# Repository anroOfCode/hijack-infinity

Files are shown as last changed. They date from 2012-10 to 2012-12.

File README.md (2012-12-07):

hijack-infinity
===============
Bidirectional Digital IO Between Microcontrollers and Smart Phones

Introduction
============
This code base is a work in progress. Currently it supports the MSP430FR5969 and MSP430F1611 microcontroller and has an Android application. 

The code for the MSP430FR5969 will not compile unless you're running on the latest build of msp430gcc. Support for other microcontrollers is in progress, and the Makefile will need to be modified to support them.

The Android app included will display some basic digital IO and analog readings, and is modular enough to form the basis of a new application.

MSP403F1611 Support
===================
Support for the MSP430F1611, compatiable with the HiJack boards sold at SeeedStudio, is at a semi-working state. Currently we operate at a rather slow baud rate, but are in-fact able to send bidirectional digital data. You'll need a way to program the HiJack board, I'd recommend using the HiJack programmer. HiJack was originally designed to be programmed with the binary serial loaded from TinyOS, take a look at the firmware installed on the Seeed studio WiKi page for an example of how to program it. Once you have the tos-bsl you can program it using the following command string:

```tos-bsl --swap-reset-test --invert-reset --invert-test -r -e -I -p out.hex```

Some issues with the current implementation
-------------------------------------------
  - The abstractions aren't the most efficient things out there, excessive computation when the periodic timer polls for a new bit causes jitter in the microcontroller-outputted signal and increases the probability for error.
  - We're using both TimerA and TimerB on the MSP430, it'd be nice to move the implementation to only use one timer and do a little bit of virtualization
  - Baud rate is a little slow, better filtering on the phone-side could help to fix this.
  - *Power draw still remains high*, this device will only be compatible with a select number of Android devices. For all other devices you will have to supply power externally. Devices that have Beats by Dr. Dre have been found to work well with HiJack, the extra amplification provides enough energy to drive the board. Supply HiJack with 2V of regulated power and disable the portion of Android code that generates the 22kHz tone for power and this code should work with many more phones.
  - Some Android devices don't support the 44.1kHz sampling rate, or have processors too slow to process the audio data in real-time. You'll either have to capture and process in blocks, or find a different phone. 

iOS Support
===========
Support for iOS is planned for the future. As of right now, the HiJack code for iOS is pretty unorganized, so refactoring it to be compatible with the communication scheme I layered on top of the basic byte-oriented interface and building the test app is something I'm still hoping to complete. 

Adding New Microcontrollers
===========================
To add support for new microcontrollers see the platform abstraction layer (lib/pal.h). This is where all the platform-specific code is placed and should be the starting point for platform-specific implementations. It should be reasonably easy to add new microcontrollers, support for the F1611 was added within a day. 

Help!
=====
This code is provided as is. Feel free to contact me with questions, however a response is not guaranteed.

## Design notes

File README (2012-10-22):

This is the home for the project to change the MSP430 on the hijack board to the new MSP430FR5969 fram based MSP

Wooo!

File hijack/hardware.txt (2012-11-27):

What needs to be done:
------------------------

For capture (decoding) of signal:

- Hook Comparator E to Timer A.
- Capture on high or low transistions over VCC/2. 
- Call some magic interrupt function for now
- Get the elapsed time from the last tigger
- Provide a way to switch from capturing on low->high transistion to high->low transition to both.

For output (encoding) of signal:

- Set TimerB to call an interrupt function
- Repeatedly. 

Capturing ADC Signals

- Whatever

Signaling Protocol:
------------------------

0xCC <- Packet start byte
0x04 <- Packet length byte
.
.
.
0x__ <- Byte addition checksum

Inner Packet Format:
--------------------
Byte 1 - 

	//if ((LED_OUT & LED_0) > 0) {
	//	LED_OUT &= ~LED_0;
	//}
	//else {
	//	LED_OUT ^= LED_0;
	//}

	*((uint16_t*) 0x1970) = 0xFFFE;
	*((uint16_t*) 0x1972) = val;
	*((uint8_t*) 0x1974) = pinValue;

void comparatorCallback (void) {
	LED_OUT ^= LED_0;
}

void byteReceiveCallback (uint8_t byte) {
	if (byte == 0xBC) {
		if ((LED_OUT & LED_0) == 0){
			LED_OUT ^= LED_0;
		} else {
			LED_OUT &= ~LED_0;
		}
	}
}

uint8_t outMessage[] = {0xDD, 0x0A, 0xFF, 0x3F, 0xFF, 0x3F, 
	0xFF, 0x3F, 0xFF, 0x2F, 0xFF, 0xE7};
uint8_t outMessagePosition = 0;

void byteSentCallback (void) {
	csm_sendByte(outMessage[outMessagePosition++]);
	if (outMessagePosition == 12) outMessagePosition = 0;
}

		//util_disableInterrupt();
		//csm_sendByte(0xBC);
		//util_enableInterrupt();
		util_delayMs(500);

	csm_sendByte(outMessage[outMessagePosition++]);		

	tos-bsl --swap-reset-test --invert-reset --invert-test -r -e -I -p out.hex

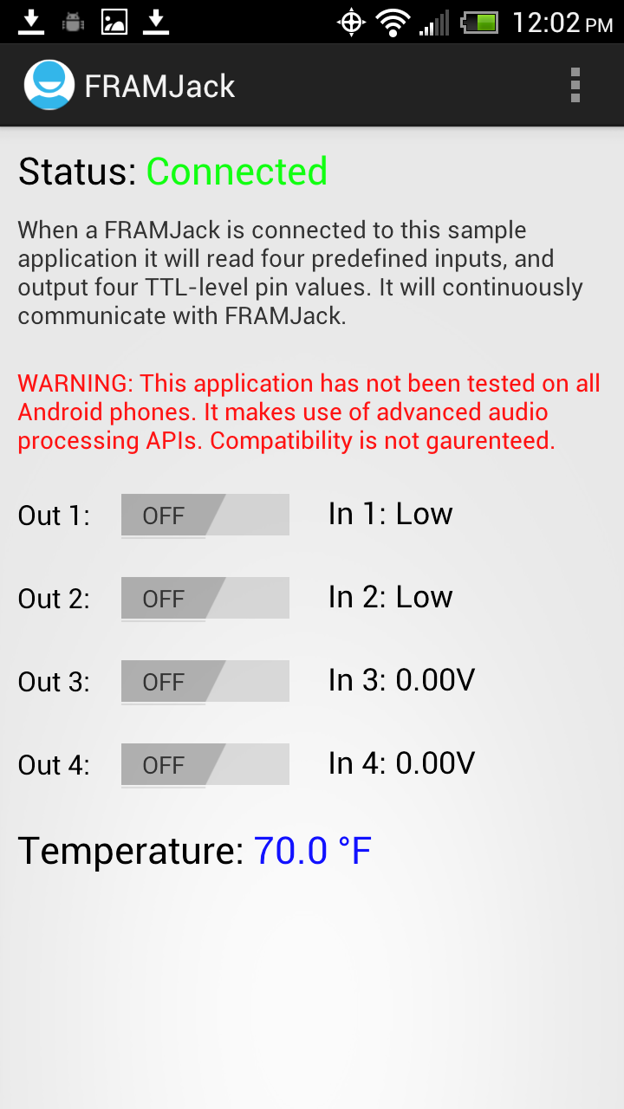
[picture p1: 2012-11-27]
screenshot.png

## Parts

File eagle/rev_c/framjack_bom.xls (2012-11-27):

Quantity | Part | Value | Device | Package | Description | Mount | Digikey | Mouser | Coilcraft
2 | C1, C2 | 0.1uF | C0603 | 0603-CAP | Capacitor | smd | 490-1524-6-ND
1 | C3 | 4.7nF | C0603 | 0603-CAP | Capacitor | smd | 490-1506-6-ND
2 | C4, C5 | 1uF | C0603 | 0603-CAP | >16V | smd | 490-3897-6-ND
3 | C6, C7, C8 | 10uF | C0603 | 0603-CAP | Capacitor | smd | 490-3896-6-ND
1 | C9 | 100uF | C0603 | 2312-CAP | >16V | smd | 399-5214-6-ND
1 | C10 | 2.2uF | C0603 | 0603-CAP | >16V | smd | 445-7438-6-ND
1 | D1 | DIODE | DIODE | MINIMELF | Shotkey Diode | smd | B5818WS-TPMSDKR-ND
1 | J1 | 3.5JACK4CONN | 3.5JACK4 | PLUGBOARDCONNECTOR | Headset Jack | thru-hole |  | 171-7435-EX
3 | J2, J3, J4 | HEADER10POS | HEADER10POS | 10PIN2MMHEADER | Socket 10Pos 2MM | thru-hole | 3M9405-ND | 517-950510-6102-AR
2 | Q1, Q2 |  | NMOSSOT23 | SOT-23 | MOS FET | smd | ZXM61N03FDKR-ND
2 | Q3, Q4 |  | PMOSSOT23 | SOT-23 | MOS FET | smd | ZXM61P03FDKR-ND
3 | R1, R2, R3 | 100k | RESISTOR0603-RES | 0603-RES | Resistor | smd | RHM100KGDKR-ND
1 | R4 | 5.1M | RESISTOR0603-RES | 0603-RES | Resistor | smd | RHM5.1MGDKR-ND
1 | R5 | 698 | RESISTOR0603-RES | 0603-RES | Resistor | smd | RHM698HDKR-ND
1 | R6 | 10k | RESISTOR0603-RES | 0603-RES | Resistor | smd | RHM10KGDKR-ND
1 | R7 | 1k | RESISTOR0603-RES | 0603-RES | Resistor | smd | RHM1.00KHDKR-ND
3 | R8, R9, R10 | 3M | RESISTOR0603-RES | 0603-RES | Resistor | smd | P3.0MGDKR-ND
1 | R11 | 1M | RESISTOR0603-RES | 0603-RES | Resistor | smd | RHM1.0MGDKR-ND
1 | R12 | 39k |  | 0603-RES | Resistor | smd | P39KGDKR-ND
1 | R13 | 255k |  | 0603-RES | Resistor | smd | P255KHDKR-ND
1 | T1 | LPR6235 | LPR6235 | LPR6235 | Transformer | smd |  |  | LPR6235-253PMLB
1 | U1 | MSP430FR5969 | MSP430F1611IPM |  | MCU | qfn | Direct from Texas Instruments
1 | U2 | MIC5231 | MIC5231 | SOT23-5 | LDO | smd | 576-2771-6-ND
1 | U3 | MAX9119 | MAX9119 | SC70-5 | Comparator | smd | MAX9119EXK+TDKR-ND
1 | U4 | MCP9700T-E/TT | MCP9700T-E/TT | SOT23-3 | Temperature Sensor | smd | MCP9700T-E/TTDKR-ND
1 | Y1 | ABS07-32.768KHZ-7-T | ABS07-32.768KHZ-7-T | ABS07-32.768KHZ-7-T | Crystal | smd | 535-9543-6-ND

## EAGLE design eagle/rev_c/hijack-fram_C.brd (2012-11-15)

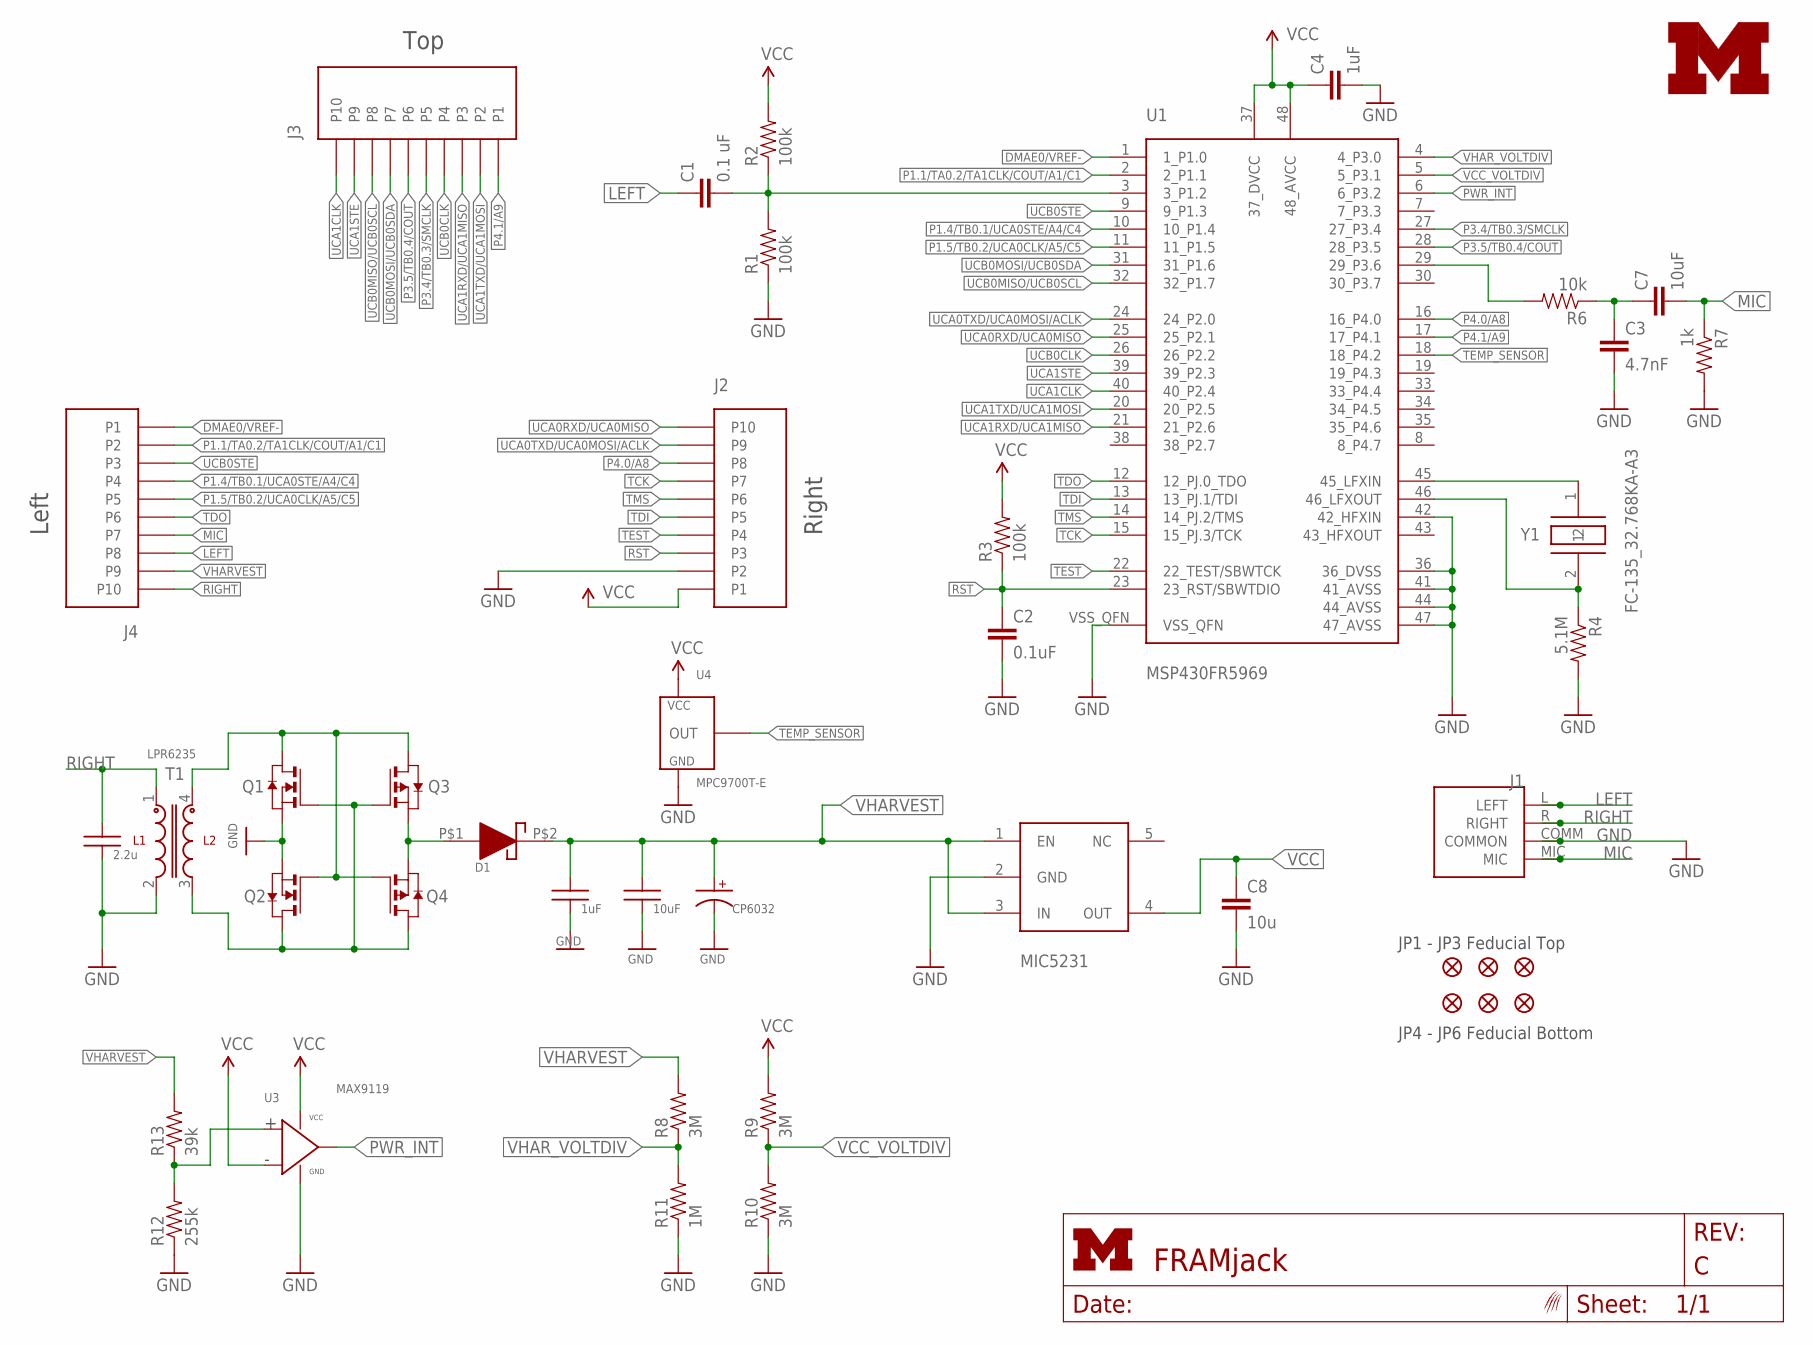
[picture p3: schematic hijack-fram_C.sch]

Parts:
C1: 0.1 uF; 0603-CAP
C2: 0.1uF; 0603-CAP
C3: 4.7nF; 0603-CAP
C4: 1uF; 0603-CAP
C5: 1uF; C0603
C6: 10uF; C0603
C7: 10uF; 0603-CAP
C8: 10u; C0603
C9: CP6032; CT6032
C10: 2.2u; C0603
D1: B5818WS-SCHOTTKY-DIODE; SOD-323
J1: 3.5JACK4CONNSUNSTONE_QUICKTURN; PLUGBOARDCONNECTOR_SUNSTONE
J2, J3, J4: HEADER10POS; 10PIN2MMHEADER
JP1, JP2, JP3, JP4, JP5, JP6: FIDUCIAL1X2; FIDUCIAL-1X2
Q1, Q2: NMOSSOT23; SOT-23
Q3, Q4: PMOSSOT23; SOT-23
R1, R2, R3: 100k; 0603-RES
R4: 5.1M; 0603-RES
R6: 10k; 0603-RES
R7: 1k; 0603-RES
R8, R9, R10: 3M; 0603-RES
R11: 1M; 0603-RES
R12: 255k; 0603-RES
R13: 39k; 0603-RES
T1: LPR6235
U1: MSP430FR5969; RGZ(S-PQFP-N48)
U2: MIC5231; SOT23-5
U3: MAX9119; SC70-5
U4: MPC9700T-E; SOT-23
U$1: WOLVERINE
U$4: UMICH_SOLID_SMALL; UMICH_SOLID_75MIL
Y1: FC-135_32.768KA-A3; FC-135

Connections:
DMAE0/VREF-: J4.P1, U1.1 (1_P1.0)
GND: C2.2, C3.2, C4.2, C5.2, C6.2, C8.2, C9.-, C10.2, J1.COMM (COMMON), J2.P2, Q1.2 (S), Q2.2 (S), R1.1, R4.2, R7.2, R10.1, R11.1, R12.1, T1.2, U1.36 (36_DVSS), U1.41 (41_AVSS), U1.42 (42_HFXIN), U1.44 (44_AVSS), U1.47 (47_AVSS), U1.VSS_QFN, U2.2 (GND), U3.2 (GND), U4.GND
LEFT: C1.1, J1.L (LEFT), J4.P8
MIC: C7.2, J1.MIC, J4.P7, R7.1
unnamed: C1.2, R1.2, R2.1, U1.3 (3_P1.2)
unnamed: R4.1, U1.46 (46_LFXOUT), Y1.2
unnamed: R6.2, U1.29 (29_P3.6)
unnamed: R12.2, R13.1, U3.3 (IN+)
unnamed: U1.45 (45_LFXIN), Y1.1
unnamed: Q1.1 (D), Q2.3 (G), Q3.1 (D), Q4.3 (G), T1.4
unnamed: Q1.3 (G), Q2.1 (D), Q3.3 (G), Q4.1 (D), T1.3
unnamed: C3.1, C7.1, R6.1
unnamed: D1.P$1 (A), Q3.2 (S), Q4.2 (S)
P1.1/TA0.2/TA1CLK/COUT/A1/C1: J4.P2, U1.2 (2_P1.1)
P1.4/TB0.1/UCA0STE/A4/C4: J4.P4, U1.10 (10_P1.4)
P1.5/TB0.2/UCA0CLK/A5/C5: J4.P5, U1.11 (11_P1.5)
P3.4/TB0.3/SMCLK: J3.P5, U1.27 (27_P3.4)
P3.5/TB0.4/COUT: J3.P6, U1.28 (28_P3.5)
P4.0/A8: J2.P8, U1.16 (16_P4.0)
P4.1/A9: J3.P1, U1.17 (17_P4.1)
PWR_INT: U1.6 (6_P3.2), U3.1 (OUT)
RIGHT: C10.1, J1.R (RIGHT), J4.P10, T1.1
RST: C2.1, J2.P3, R3.1, U1.23 (23_RST/SBWTDIO)
TCK: J2.P7, U1.15 (15_PJ.3/TCK)
TDI: J2.P5, U1.13 (13_PJ.1/TDI)
TDO: J4.P6, U1.12 (12_PJ.0_TDO)
TEMP_SENSOR: U1.18 (18_P4.2), U4.VOUT (OUT)
TEST: J2.P4, U1.22 (22_TEST/SBWTCK)
TMS: J2.P6, U1.14 (14_PJ.2/TMS)
UCA0RXD/UCA0MISO: J2.P10, U1.25 (25_P2.1)
UCA0TXD/UCA0MOSI/ACLK: J2.P9, U1.24 (24_P2.0)
UCA1CLK: J3.P10, U1.40 (40_P2.4)
UCA1RXD/UCA1MISO: J3.P3, U1.21 (21_P2.6)
UCA1STE: J3.P9, U1.39 (39_P2.3)
UCA1TXD/UCA1MOSI: J3.P2, U1.20 (20_P2.5)
UCB0CLK: J3.P4, U1.26 (26_P2.2)
UCB0MISO/UCB0SCL: J3.P8, U1.32 (32_P1.7)
UCB0MOSI/UCB0SDA: J3.P7, U1.31 (31_P1.6)
UCB0STE: J4.P3, U1.9 (9_P1.3)
VCC: C4.1, C8.1, J2.P1, R2.2, R3.2, R9.2, U1.37 (37_DVCC), U1.48 (48_AVCC), U2.4 (OUT), U3.4 (IN-), U3.5 (VCC), U4.VDD (VCC)
VCC_VOLTDIV: R9.1, R10.2, U1.5 (5_P3.1)
VHARVEST: C5.1, C6.1, C9.+, D1.P$2 (C), J4.P9, R8.2, R13.2, U2.1 (EN), U2.3 (IN)
VHAR_VOLTDIV: R8.1, R11.2, U1.4 (4_P3.0)

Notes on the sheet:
Left
Top
Right
JP1 - JP3 Feducial Top
JP4 - JP6 Feducial Bottom

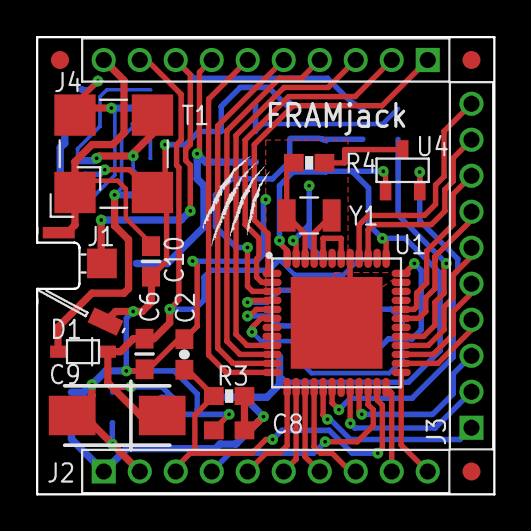
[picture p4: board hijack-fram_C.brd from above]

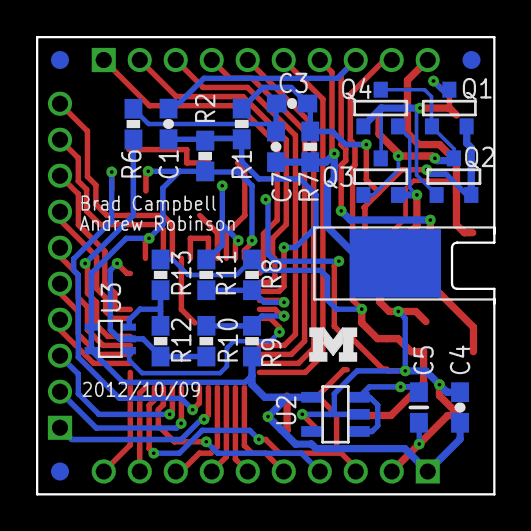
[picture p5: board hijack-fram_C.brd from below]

Board: 2 copper layers, 25.4 x 25.4 mm, 45 parts (25 on the bottom side), 43 nets.

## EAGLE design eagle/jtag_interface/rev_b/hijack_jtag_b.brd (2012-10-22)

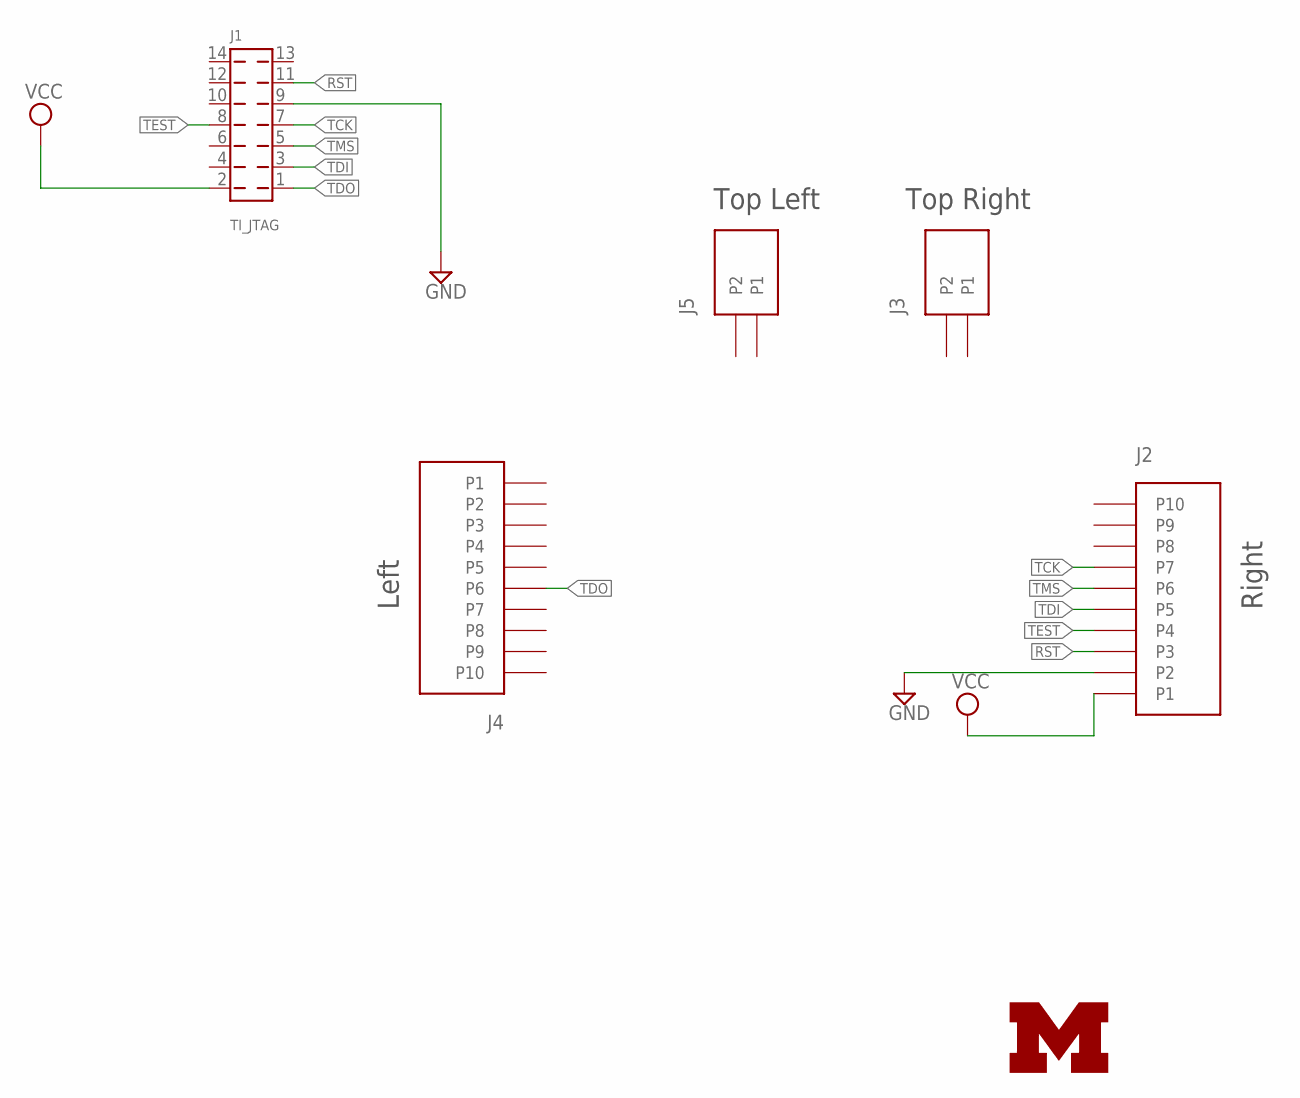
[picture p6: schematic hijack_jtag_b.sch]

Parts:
J1: TI_JTAG; TST-107
J2, J4: HEADER10POS; 10PIN2MMHEADER
J3, J5: HEADER2POS; 2PIN2MMHEADER
U$2: UMICH_SOLID

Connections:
GND: J1.9, J2.P2
RST: J1.11, J2.P3
TCK: J1.7, J2.P7
TDI: J1.3, J2.P5
TDO: J1.1, J4.P6
TEST: J1.8, J2.P4
TMS: J1.5, J2.P6
VCC: J1.2, J2.P1

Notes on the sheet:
Left
Right
Top Left
Top Right

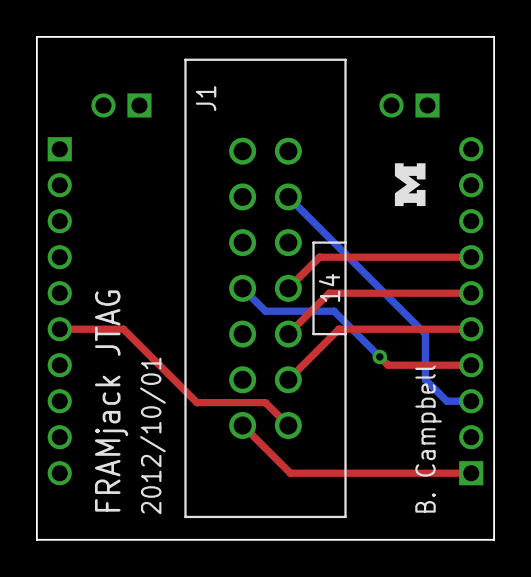
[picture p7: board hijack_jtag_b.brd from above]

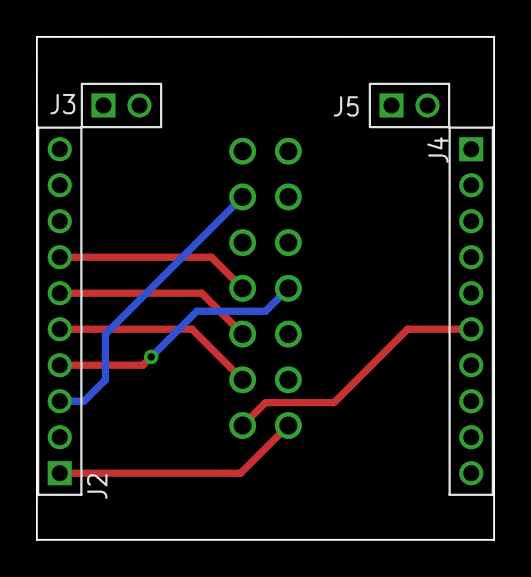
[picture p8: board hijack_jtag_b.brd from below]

Board: 2 copper layers, 25.4 x 27.9 mm, 6 parts (4 on the bottom side), 8 nets.

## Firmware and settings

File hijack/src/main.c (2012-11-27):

/*
 *  This file is part of hijack-infinity.
 *
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
 *  You should have received a copy of the GNU General Public License
 *  along with hijack-infinity.  If not, see <http://www.gnu.org/licenses/>.
 */

#include <inttypes.h>
#include <stdio.h>

#include "pal.h"
#include "codingStateMachine.h"
#include "framingEngine.h"

uint8_t outMessage[] = {
	0xFF, 		// Make the first 2 bits of this
				// equal to the state of two input pins.
	0x3F, 0xFF, // Analog In 1
	0x3F, 0xFF, // Analog In 2
	0x3F, 0xFF, // Analog In 3 (temperature)
	0x2F, 0xFF  // Analog In 4 (potentially a v_ref)
};

uint16_t temp_buf[100] = {0};
uint8_t buf_idx= 0;

void periodicTimerFn (void) {

	uint8_t ats;
	ats = csm_advanceTransmitState();

	if (ats) {
		pal_setDigitalGpio(pal_gpio_mic, 1);
	} else {
		pal_setDigitalGpio(pal_gpio_mic, 0);
	}

	csm_finishAdvanceTransmitState();
}

void captureTimerFn(uint16_t elapsedTime, uint8_t isHigh) {
	struct csm_timer_struct timingData;
	timingData.elapsedTime = elapsedTime;
	timingData.signal = !isHigh;
	csm_receiveTiming(&timingData);	
}

void packetReceivedCallback(uint8_t * buf, uint8_t len) {
	if (len == 1) {
		pal_setDigitalGpio(pal_gpio_led, 1);
		pal_setDigitalGpio(pal_gpio_dout1, ((buf[0] >> 0) & 0x01));
		pal_setDigitalGpio(pal_gpio_dout2, ((buf[0] >> 1) & 0x01));
		pal_setDigitalGpio(pal_gpio_dout3, ((buf[0] >> 2) & 0x01));
		pal_setDigitalGpio(pal_gpio_dout4, ((buf[0] >> 3) & 0x01));
	}
}

void packetSentCallback(void) {
	fe_writeTxBuffer(outMessage, 9);
}

void updateAnalogOutputBuffer(void) {
	//pal_sampleAnalogGpios();
	uint16_t temp_ext = 0;
	uint16_t vcc = 0;
	uint16_t sample1 = 0;
	uint16_t sample2 = 0;

	//vcc = pal_readAnalogGpio(pal_gpio_vref);
	//temp_ext = pal_readAnalogGpio(pal_gpio_temp);
	//sample1 = pal_readAnalogGpio(pal_gpio_ain1);
	//sample2 = pal_readAnalogGpio(pal_gpio_ain2);

	outMessage[1] = vcc & 0xFF;
	outMessage[2] = (vcc >> 8) & 0xFF;
	outMessage[3] = temp_ext & 0xFF;
	outMessage[4] = (temp_ext >> 8) & 0xFF;
	outMessage[5] = sample1 & 0xFF;
	outMessage[6] = (sample1 >> 8) & 0xFF;
	outMessage[7] = sample2 & 0xFF;
	outMessage[8] = (sample2 >> 8) & 0xFF;
}

void updateDigitalOutputBuffer(void) {
	outMessage[0] = (outMessage[0] & ~(1 << 0)) |
		((pal_readDigitalGpio(pal_gpio_din1) & 0x1) << 0);
	outMessage[0] = (outMessage[0] & ~(1 << 1)) |
		((pal_readDigitalGpio(pal_gpio_din2) & 0x1) << 1);
}

void initializeSystem(void) {
	pal_init();

	// Initialize the transition-edge-length
	// manchester decoder.
	csm_init();
	csm_registerReceiveByte(fe_handleByteReceived);
	csm_registerTransmitByte(fe_handleByteSent);

	// Initialize the framing engine to process
	// the raw byte stream.
	fe_init();
	fe_registerPacketReceivedCb(packetReceivedCallback);
	fe_registerPacketSentCb(packetSentCallback);
	fe_registerByteSender(csm_sendByte);

	pal_registerPeriodicTimerCb(periodicTimerFn);
	pal_registerCaptureTimerCb(captureTimerFn);

	// Start the interrupt-driven timers.
	pal_startTimers();

	// Start the transmit callback-driven
	// loop
	fe_writeTxBuffer(outMessage, 9);
	fe_startSending();
}

// This is the main loop. It's not very
// power efficient right now, it should
// do some microcontroller sleep commands
// and use wakeups.
int main () {
	initializeSystem();
	// TODO: Add sleep commands!

		/*while(1)
	{
		pal_setDigitalGpio(pal_gpio_led, 1);
		pal_setDigitalGpio(pal_gpio_led, 0);
	}*/


	while(1) {
		//pal_setDigitalGpio(pal_gpio_led, 0);
		updateDigitalOutputBuffer();
		updateAnalogOutputBuffer();
		//pal_setDigitalGpio(pal_gpio_led, 1);
		pal_loopDelay();

	}
    return 0;
}

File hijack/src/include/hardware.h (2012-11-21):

/*
 *  This file is part of hijack-infinity.
 *
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
 *  You should have received a copy of the GNU General Public License
 *  along with hijack-infinity.  If not, see <http://www.gnu.org/licenses/>.
 */

// Hardware Pin Mappings for boards:
///////////////////////////////////////
// HIJACK REVD BOARD WITH MSP430F1611:
//
// Digital In 1: J4 (left), P1
// Digital In 2: J4 (left), P2
// Digital Out 1: J4 (left), P3
// Digital Out 2: J4 (left), P4
// Digital Out 3: J4 (left), P5
// Digital Out 4: J4 (left), P6
// Analog In 1: J2 (right), P5
// Analog In 2: J2 (right), P6
// 
//////////////////////////////////////

#ifndef __HARDWARE_H__
#define __HARDWARE_H__

#include "config.h"

#ifdef MSP430FR5969

#define LED_0 BIT0
#define LED_OUT P1OUT
#define LED_DIR P1DIR

#define LED_PORT 1
#define LED_PIN 0

#define MIC_PORT 3
#define MIC_PIN 6

#define LEFT_PORT 1
#define LEFT_PIN 2

#define VREF_PORT 3
#define VREF_PIN 1

#define OUT1_PORT 2
#define OUT1_PIN 4

#define OUT2_PORT 2
#define OUT2_PIN 3

#define OUT3_PORT 1
#define OUT3_PIN 7

#define OUT4_PORT 1
#define OUT4_PIN 6

#define AIN1_PORT 1
#define AIN1_PIN 4

#define AIN2_PORT 1
#define AIN2_PIN 5

#define TEMP_PORT 4
#define TEMP_PIN 2

#define DIN1_PORT 3
#define DIN1_PIN 5

#define DIN2_PORT 3
#define DIN2_PIN 4

#define AIN1_ACH 4
#define AIN2_ACH 5
#define TEMP_ACH 10
#define VREF_ACH 13

#endif

#ifdef MSP430F1611

#define LED_PORT 1
#define LED_PIN 2

#define MIC_PORT 4
#define MIC_PIN 0

#define LEFT_PORT 2
#define LEFT_PIN 3

#define VREF_PORT 6
#define VREF_PIN 1

#define OUT1_PORT 5
#define OUT1_PIN 0

#define OUT2_PORT 5
#define OUT2_PIN 1

#define OUT3_PORT 5
#define OUT3_PIN 2

#define OUT4_PORT 5
#define OUT4_PIN 3

#define AIN1_PORT 6
#define AIN1_PIN 4

#define AIN2_PORT 6
#define AIN2_PIN 5

#define TEMP_PORT 6
#define TEMP_PIN 6

#define DIN1_PORT 4
#define DIN1_PIN 5

#define DIN2_PORT 4
#define DIN2_PIN 6

#define AIN1_ACH 4
#define AIN2_ACH 5
#define TEMP_ACH 6
#define VREF_ACH 1

#endif

#endif

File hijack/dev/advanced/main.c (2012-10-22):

#include "msp430.h"

void board_init(void);


int main(void) {

	WDTCTL = WDTPW + WDTHOLD;

	board_init();

	__bis_SR_register(CPUOFF);

}


void board_init(void)

{
	  P1DIR = 0;
	  P1OUT = 0;
	  P1REN = 0xFF;

	  P2DIR = 0;
	  P2OUT = 0;
	  P2REN = 0xFF;

	  P3DIR = 0;
	  P3OUT = 0;
	  P3REN = 0xFF;

	  P4DIR = 0;
	  P4OUT = 0;
	  P4REN = 0xFF;

	  PJDIR = 0;
	  PJOUT = 0;
	  PJREN = 0xFF;

	  CSCTL0_H = 0xA5;
	  CSCTL1 = DCOFSEL_0;                   // Set DCO= 1MHz
	  CSCTL1 &= ~DCORSEL;
	  CSCTL2 = SELA__VLOCLK + SELS__DCOCLK + SELM__DCOCLK;
	  CSCTL3 = DIVA__1 + DIVS__1 + DIVM__1; // set all dividers
	  CSCTL4 = LFXTOFF | HFXTOFF;
	  CSCTL5 &= ~(LFXTOFFG | HFXTOFFG);

}

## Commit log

2012-10-22 Initial commit of hijack-infinity work.
    [framjack_bom.xls, hijack-fram_A.brd, hijack-fram_A.sch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]
2012-11-15 small fix to framingEngine
    [hijack-fram_C.brd]
2012-11-26 adding timer initialization code
2012-11-27 optimization turned on... up to 100 B/s transmission
    [framjack_bom.xls, hijack_jtag_b.sch]

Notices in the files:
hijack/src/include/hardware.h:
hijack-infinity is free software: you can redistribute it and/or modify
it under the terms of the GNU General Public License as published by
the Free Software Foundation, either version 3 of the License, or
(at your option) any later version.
